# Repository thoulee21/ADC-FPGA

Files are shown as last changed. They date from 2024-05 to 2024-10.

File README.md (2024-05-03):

# Σ-Δ ADC 数模混合电路模型

## 介绍
1. 工程基于lattice提供的方案。  
[lattice提供的方案](https://www.latticesemi.com/products/designsoftwareandip/intellectualproperty/referencedesigns/referencedesign03/simplesigmadeltaadc)  
2. 本工程致力于以下两个目标：  
- 使用实例帮助初学者理解Σ-Δ(Sigma-Delta)ADC的原理  
- 在FPGA上使用简单的外围电路，实现AD转换  
3. 实现所需的器件
- 一个运放或比较器  
- 电容电阻  
- 一个FPGA  

## 系统架构
#### 逻辑结构
输入图片说明  
Σ-Δ ADC一眼看上去，都看不出能AD转换，给人一种“这真的是ADC吗”的感觉。  
本人才疏学浅，大神讲解得更深入：[B站链接](https://www.bilibili.com/video/BV1PV41127QD)  
#### 外围电路
外围电路 批注 2021-11-17 17120.jpg  
显而易见，这是一个比较器，或者是一个工作在比较器状态的运放。  
模拟信号连接至正相输入端，反馈信号经过RC滤波连接至反相输入端，比较器输出连接至FPGA。  
RC滤波器是一个低通滤波器，截止频率与ADC的采样速率和FPGA工作频率有关。
#### 数字设计
外围电路将模拟信号转换为1位的01序列，这样我们就能用数字逻辑去处理模拟信号。  
1. 使用一个累加器，统计一段固定长度序列中1的个数。通过这种方法，可以将01序列转换为一段序列的占空比。累加器宽度由ACCUM_BITS决定。  
2. 占空比信号是有波动的，后端使用一个均值滤波器去除毛刺，滤波器越深，信号速率越低，精度越高。滤波器深度由LPF_DEPTH_BITS决定。  
3. ADC_WIDTH参数贯穿始终，它是ADC的位宽。  
## 使用教程
#### 逻辑仿真
windows环境，需要安装iverilog。  
clone项目，进入`RTL/tb`，运行`make.bat`  
#### 制作实物
k7_fpga.rar是vivado 2019.2的工程，配合`硬件电路/`提供的原理图，可以实现Σ-Δ ADC。  
#### 输出时序
输入图片说明  
## 演示
使用7k325连接外围电路，采集电压，8bit输出。内置逻辑分析仪查看情况。  
sample_rdy高电平脉冲表示一次转换结束，输出结果为0x6d。  
实验的ADC位宽为8bit，量程是0-3.3V，那么实际电压为`0x6d/0xff*3.3=1.41v`，与万用表测量结果吻合。
ILA界面 批注 2021-11-17 184927.jpg

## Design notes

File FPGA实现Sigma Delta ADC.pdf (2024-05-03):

## 通过高速比较器和FPGA逻辑实现 Sigma Delta ADC - 基于电赛综合

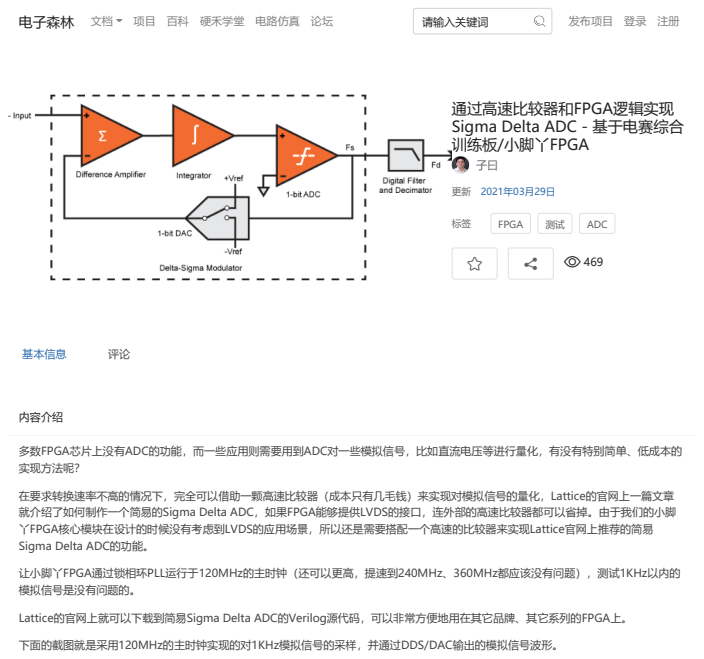
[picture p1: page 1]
训练板/小脚丫FPGA; FPGA; ADC; 基本信息; 内容介绍; 让小脚丫FPGA通过锁相环PLL运行于120MHz的主时钟（还可以更高，提速到240MHz、360MHz都应该没有问题），测试1KHz以内的 模拟信号是没有问题的。; 下面的截图就是采用120MHz的主时钟实现的对1KHz模拟信号的采样，并通过DDS/DAC输出的模拟信号波形。; 电子森林 文档; 项目 百科 硬禾学堂 电路仿真 论坛; 请输入关键词; 发布项目 登录 注册

多数FPGA芯片上没有ADC的功能，而一些应用则需要用到ADC对一些模拟信号，比如直流电压等进行量化，有没有特别简单、低成本的
实现方法呢？

在要求转换速率不高的情况下，完全可以借助一颗高速比较器（成本只有几毛钱）来实现对模拟信号的量化，Lattice的官网上一篇文章
就介绍了如何制作一个简易的Sigma Delta ADC，如果FPGA能够提供LVDS的接口，连外部的高速比较器都可以省掉。由于我们的小脚
丫FPGA核心模块在设计的时候没有考虑到LVDS的应用场景，所以还是需要搭配一个高速的比较器来实现Lattice官网上推荐的简易
Sigma Delta ADC的功能。

Lattice的官网上就可以下载到简易Sigma Delta ADC的Verilog源代码，可以非常方便地用在其它品牌、其它系列的FPGA上。

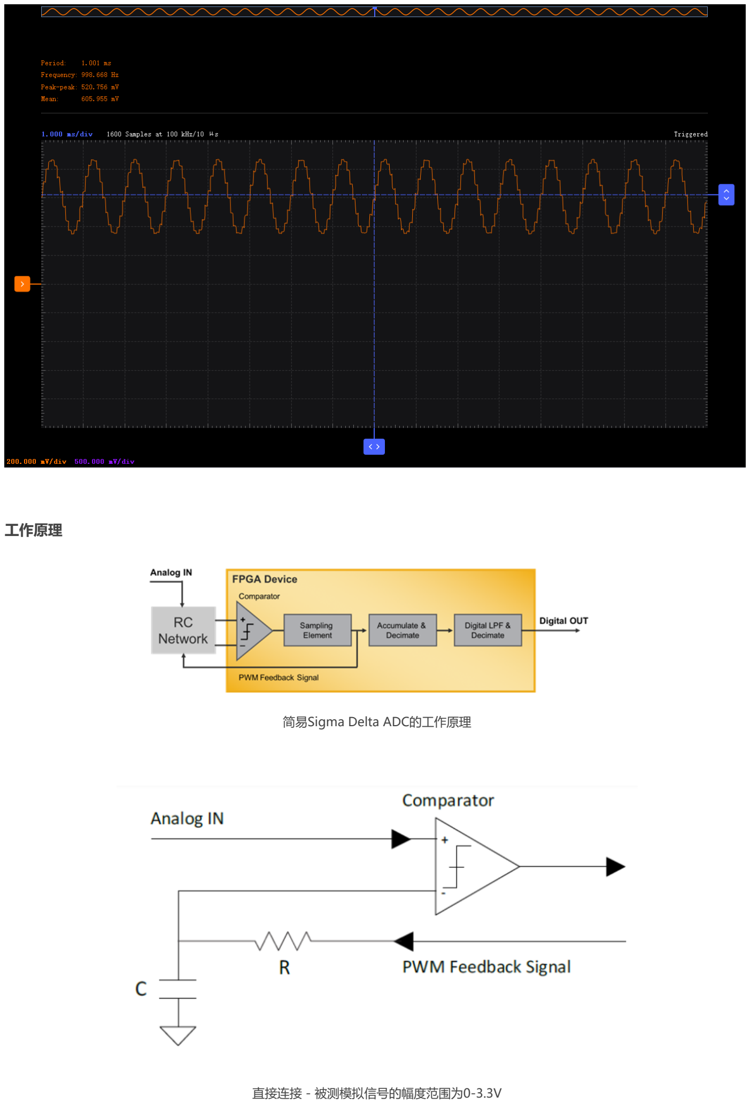
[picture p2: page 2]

### 工作原理

简易Sigma Delta ADC的工作原理

直接连接 - 被测模拟信号的幅度范围为0-3.3V

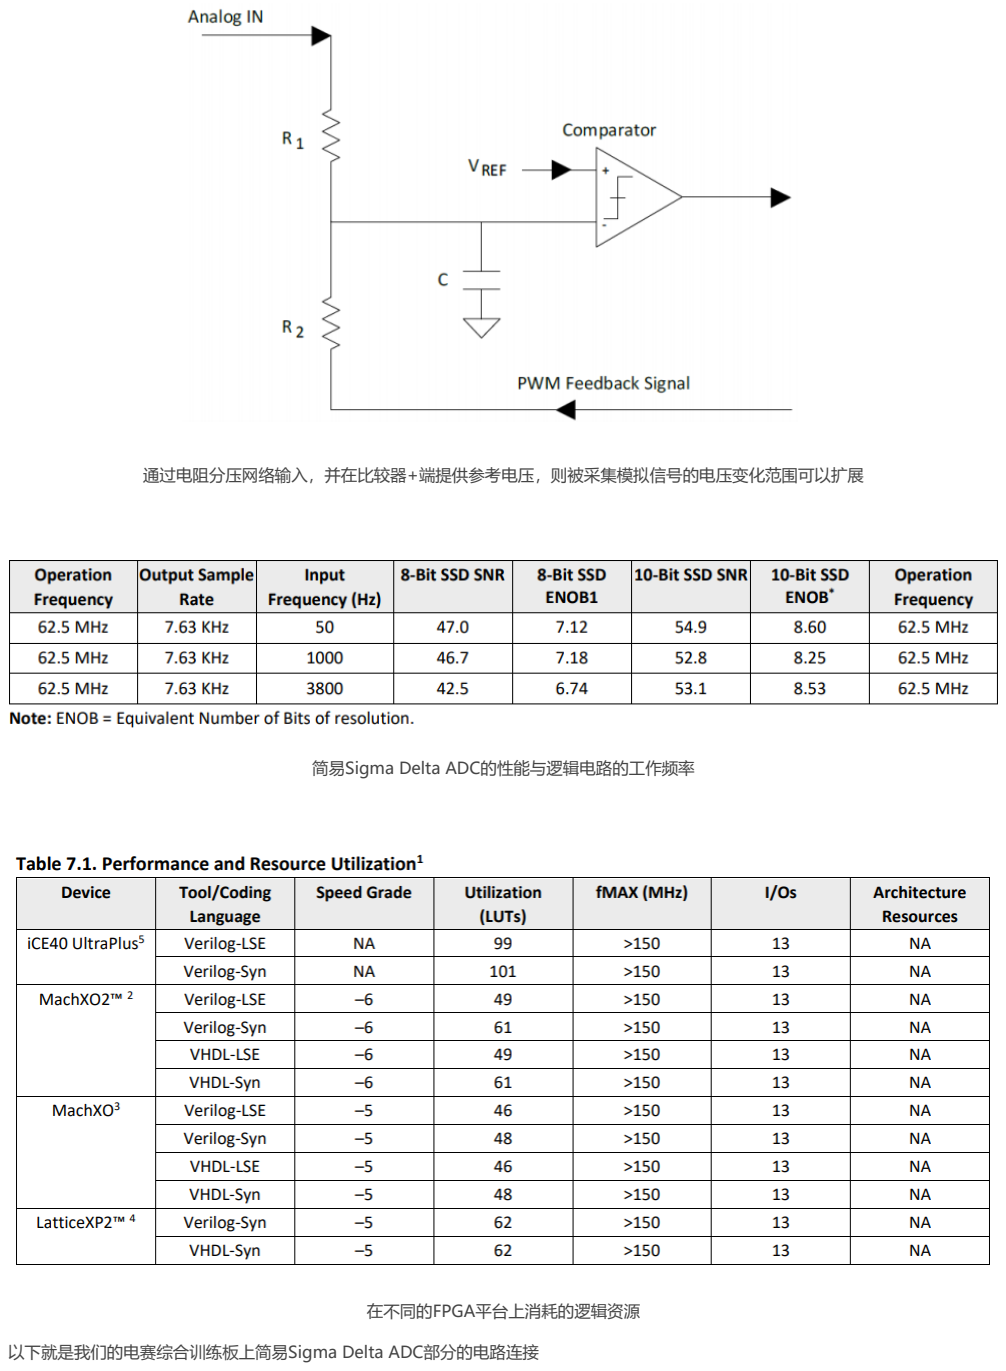
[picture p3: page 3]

通过电阻分压网络输入，并在比较器+端提供参考电压，则被采集模拟信号的电压变化范围可以扩展

简易Sigma Delta ADC的性能与逻辑电路的工作频率

在不同的FPGA平台上消耗的逻辑资源

以下就是我们的电赛综合训练板上简易Sigma Delta ADC部分的电路连接

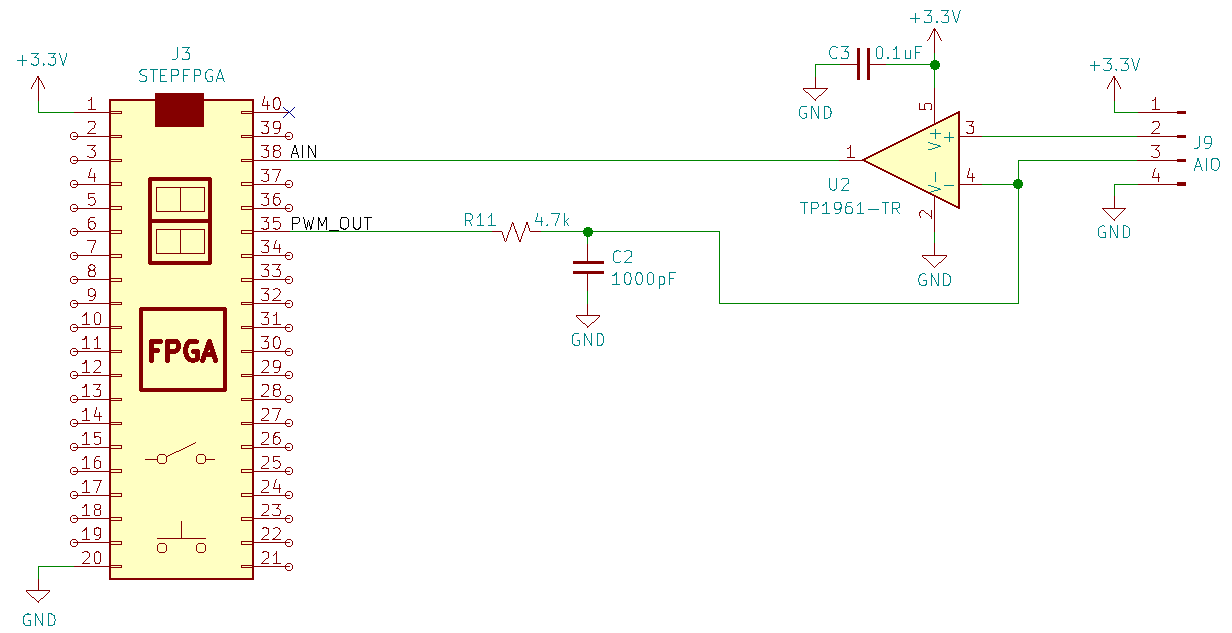
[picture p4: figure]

参考文章：

关键代码：

顶层调用代码：

Sigma Delta ADC顶层程序

wire [7:0] sd_adc_out; // sigma delta adc data output

wire sample_rdy; // flag for adc conversion

ADC_top my_adc(.clk_in(clk_hs),.rstn(1'b1),.digital_out(sd_adc_out), .analog_cmp(comp_in),.analog_out(ad_pwm),.sample_rdy(

assign dac_data | = | sd_adc_out;
assign dac_clk | = | clk_hs; //120MHz generated by PLL
- The basics of sigma delta analog-to-digital converters (https://www.embedded.com/the-basics-of-sigma-delta-analog-to-digital-converters/)
- TEARING INTO DELTA SIGMA ADC’S (https://hackaday.com/2016/07/07/tearing-into-delta-sigma-adcs-part-1/)

// ================================================================== // >>>>>>>>>>>>>>>>>>>>>>> COPYRIGHT NOTICE <<<<<<<<<<<<<<<<<<<<<<<<<
// ------------------------------------------------------------------
// Copyright (c) 2014 by Lattice Semiconductor Corporation
// ALL RIGHTS RESERVED
// ------------------------------------------------------------------//
// Permission:
//
// | Lattice SG Pte. Ltd. grants permission to use this code
// | pursuant to the terms of the Lattice Reference Design License Agreement.
//
//
// Disclaimer:
//
// | This VHDL or Verilog source code is intended as a design reference
// | which illustrates how these types of functions can be implemented.
// | It is the user's responsibility to verify their design for
// | consistency and functionality through the use of formal
// | verification methods. Lattice provides no warranty
// | regarding the use or functionality of this code.
//
// --------------------------------------------------------------------//
// | Lattice SG Pte. Ltd.
// | 101 Thomson Road, United Square #07-02
// | Singapore 307591
//
//
// | TEL: 1-800-Lattice (USA and Canada)
// | +65-6631-2000 (Singapore)
// | +1-503-268-8001 (other locations)
//
// | web: http://www.latticesemi.com/
// | email: techsupport@latticesemi.com
//
// --------------------------------------------------------------------//
// Project: ADC_lvds
// File: | adc_top.v
// Title: | ADC Top Level
// Description: Top level of Analog to Digital Convertor
//
// --------------------------------------------------------------------//
// Revision History :
// --------------------------------------------------------------------
// $Log: RD#rd1066_simple_sigma_delta_adc#rd1066#source#verilog#adc_top.v,v $
// Revision 1.1 2015-02-05 00:00:56-08 mbevinam
// Updated RD Placed in RD Folder. Previous versions are in RD_Dimensions Archive folder. //
// Revision Date
// 1.0 10/12/2009 Initial Revision
//
// --------------------------------------------------------------------

//********************************************************************* //

// ADC Top Level Module
//
//*********************************************************************

module ADC_top (
clk_in,
rstn,
digital_out,
analog_cmp,
analog_out,
sample_rdy);

parameter
ADC_WIDTH | = | 8, | // ADC Convertor Bit Precision
ACCUM_BITS | = | 10, | // 2^ACCUM_BITS is decimation rate of accumulator
LPF_DEPTH_BITS | = | 3, | // 2^LPF_DEPTH_BITS is decimation rate of averager
INPUT_TOPOLOGY | = | 1; | // 0: DIRECT: Analog input directly connected to + input of comparitor
// 1: NETWORK:Analog input connected through R divider to - input of comp.

//input ports
input | clk_in; | // 62.5Mhz on Control Demo board
input | rstn;
input | analog_cmp; | // from LVDS buffer or external comparitor

//output ports
output analog_out; | // feedback to RC network
output sample_rdy;
output [7:0] digital_out; // connected to LED field on control demo bd.

//**********************************************************************
//
// Internal Wire & Reg Signals
//
//**********************************************************************
wire | clk;
wire | analog_out_i;
wire | sample_rdy_i;
wire [ADC_WIDTH-1:0] | digital_out_i;
wire [ADC_WIDTH-1:0] | digital_out_abs;
assign clk | = | clk_in;

//*********************************************************************** //
// SSD ADC using onboard LVDS buffer or external comparitor
//
//*********************************************************************** sigmadelta_adc #(
.ADC_WIDTH(ADC_WIDTH),
.ACCUM_BITS(ACCUM_BITS),
.LPF_DEPTH_BITS(LPF_DEPTH_BITS) )
SSD_ADC(
.clk(clk),

.rstn(rstn),
.analog_cmp(analog_cmp),
.digital_out(digital_out_i), .analog_out(analog_out_i),
.sample_rdy(sample_rdy_i)
);
assign digital_out_abs | = | INPUT_TOPOLOGY | ? | ~digital_out_i : digital_out_i;

//***********************************************************************
//
// output assignments
//
//***********************************************************************
assign digital_out | = | ~digital_out_abs; | // invert bits for LED display
assign analog_out | = | analog_out_i;
assign sample_rdy | = | sample_rdy_i;

endmodule

Sigma Delta ADC主程序

// ================================================================== // >>>>>>>>>>>>>>>>>>>>>>> COPYRIGHT NOTICE <<<<<<<<<<<<<<<<<<<<<<<<<
// ------------------------------------------------------------------
// Copyright (c) 2014 by Lattice Semiconductor Corporation
// ALL RIGHTS RESERVED
// ------------------------------------------------------------------//
// Permission:
//
// | Lattice SG Pte. Ltd. grants permission to use this code
// | pursuant to the terms of the Lattice Reference Design License Agreement.
//
//
// Disclaimer:
//
// | This VHDL or Verilog source code is intended as a design reference
// | which illustrates how these types of functions can be implemented.
// | It is the user's responsibility to verify their design for
// | consistency and functionality through the use of formal
// | verification methods. Lattice provides no warranty
// | regarding the use or functionality of this code.
//
// --------------------------------------------------------------------//
// | Lattice SG Pte. Ltd.
// | 101 Thomson Road, United Square #07-02
// | Singapore 307591
//
//
// | TEL: 1-800-Lattice (USA and Canada)
// | +65-6631-2000 (Singapore)
// | +1-503-268-8001 (other locations)
//
// | web: http://www.latticesemi.com/
// | email: techsupport@latticesemi.com
//
// --------------------------------------------------------------------// --------------------------------------------------------------------//
// Project: Simple Sigma Delta (SSD)
// File: | sigmadelta_adc.v
// Title: | SSD Top Level
// Description: Top level of SSD Analog to Digital Convertor //
// --------------------------------------------------------------------//
// Revision History :
// --------------------------------------------------------------------
// $Log: rd1066#source#verilog#sigmadelta_adc.v,v $
// Revision 1.1 2015-02-05 00:00:52-08 mbevinam
// Updated RD Placed in RD Folder. Previous versions are in RD_Dimensions Archive folder. //
// Revision Date
// 1.0 10/12/2009 Initial Revision
//
// --------------------------------------------------------------------

//*********************************************************************

//
// SSD Top Level Module
//
//*********************************************************************

module sigmadelta_adc (
clk,
rstn,
digital_out,
analog_cmp,
analog_out,
sample_rdy);

parameter
ADC_WIDTH | = | 8, | // ADC Convertor Bit Precision
ACCUM_BITS | = | 10, | // 2^ACCUM_BITS is decimation rate of accumulator
LPF_DEPTH_BITS | = | 3; | // 2^LPF_DEPTH_BITS is decimation rate of averager

//input ports
input | clk; | // sample rate clock
input | rstn; | // async reset, asserted low
input | analog_cmp ; | // input from LVDS buffer (comparitor)

//output ports
output analog_out; | // feedback to comparitor input RC circuit
output sample_rdy; | // digital_out is ready
output [ADC_WIDTH-1:0] | digital_out; | // digital output word of ADC

//**********************************************************************
//
// Internal Wire & Reg Signals
//
//**********************************************************************
reg | delta; | // captured comparitor output
reg [ACCUM_BITS-1:0] | sigma; | // running accumulator value
reg [ADC_WIDTH-1:0] | accum; | // latched accumulator value
reg [ACCUM_BITS-1:0] | counter; | // decimation counter for accumulator
reg | rollover; | // decimation counter terminal count
reg | accum_rdy; | // latched accumulator value 'ready'

//*********************************************************************** //
// SSD 'Analog' Input - PWM
//
// External Comparator Generates High/Low Value
//
//***********************************************************************

always @ (posedge clk)
begin
delta | <= | analog_cmp; | // capture comparitor output
end
assign analog_out | = | delta; | // feedback to comparitor LPF

//*********************************************************************** //
// Accumulator Stage
//
// Adds PWM positive pulses over accumulator period
//
//***********************************************************************

always @ (posedge clk or negedge rstn)
begin
if( ~rstn )
begin
sigma | <= | 0;
accum | <= | 0;
accum_rdy | <= | 0;
end else begin
if (rollover) begin
// latch top ADC_WIDTH bits of sigma accumulator (drop LSBs)
accum | <= | sigma[ACCUM_BITS-1:ACCUM_BITS-ADC_WIDTH];
sigma | <= | delta; | // reset accumulator, prime with current delta value
end else begin
if (&sigma | != | 1'b1) | | // if not saturated
sigma | <= | sigma | + | delta; // accumulate
end
accum_rdy | <= | rollover; | // latch 'rdy' (to align with accum)
end
end

//*********************************************************************** //
// Box filter Average
//
// Acts as simple decimating Low-Pass Filter
//
//***********************************************************************

box_ave #(
.ADC_WIDTH(ADC_WIDTH),
.LPF_DEPTH_BITS(LPF_DEPTH_BITS))
box_ave (
.clk(clk),
.rstn(rstn),
.sample(accum_rdy),
.raw_data_in(accum),
.ave_data_out(digital_out),
.data_out_valid(sample_rdy)
);

//************************************************************************ //
// Sample Control - Accumulator Timing
//
//************************************************************************

always @(posedge clk or negedge rstn)
begin
if( | ~rstn ) begin
counter | <= | 0;

rollover | <= | 0;
end
else begin
counter | <= | counter | + | 1; | // running count
rollover | <= | &counter; | // assert 'rollover' when counter is all 1's
end
end

endmodule

数字低通滤波器模块，做平滑滤波

// ================================================================== // >>>>>>>>>>>>>>>>>>>>>>> COPYRIGHT NOTICE <<<<<<<<<<<<<<<<<<<<<<<<<
// ------------------------------------------------------------------
// Copyright (c) 2014 by Lattice Semiconductor Corporation
// ALL RIGHTS RESERVED
// ------------------------------------------------------------------//
// Permission:
//
// | Lattice SG Pte. Ltd. grants permission to use this code
// | pursuant to the terms of the Lattice Reference Design License Agreement.
//
//
// Disclaimer:
//
// | This VHDL or Verilog source code is intended as a design reference
// | which illustrates how these types of functions can be implemented.
// | It is the user's responsibility to verify their design for
// | consistency and functionality through the use of formal
// | verification methods. Lattice provides no warranty
// | regarding the use or functionality of this code.
//
// --------------------------------------------------------------------//
// | Lattice SG Pte. Ltd.
// | 101 Thomson Road, United Square #07-02
// | Singapore 307591
//
//
// | TEL: 1-800-Lattice (USA and Canada)
// | +65-6631-2000 (Singapore)
// | +1-503-268-8001 (other locations)
//
// | web: http://www.latticesemi.com/
// | email: techsupport@latticesemi.com
//
// --------------------------------------------------------------------// --------------------------------------------------------------------//
// Project: ADC_lvds
// File: | box_ave.v
// Title: | Box Filter Average
// Description: Returns average of last N samples, with /N decimation //
// --------------------------------------------------------------------
//
// Revision History :
// --------------------------------------------------------------------
// $Log: RD#rd1066_simple_sigma_delta_adc#rd1066#source#verilog#box_ave.v,v $
// Revision 1.1 2015-02-05 00:00:54-08 mbevinam
// Updated RD Placed in RD Folder. Previous versions are in RD_Dimensions Archive folder. //
// Revision Date
// 1.0 10/16/2009 S. Hossner Initial Revision
//
// --------------------------------------------------------------------

//*********************************************************************

//
// 'Box' Average
//
// Standard Mean Average Calculation
// Can be modeled as FIR Low-Pass Filter where
// all coefficients are equal to '1'.
//
//*********************************************************************

module box_ave (
clk,
rstn,
sample,
raw_data_in,
ave_data_out,
data_out_valid);

parameter
ADC_WIDTH | = | 8, | // ADC Convertor Bit Precision
LPF_DEPTH_BITS | = | 4; | // 2^LPF_DEPTH_BITS is decimation rate of averager

//input ports
input | clk; | // sample rate clock
input | rstn; | // async reset, asserted low
input | sample; | // raw_data_in is good on rising edge,
input | [ADC_WIDTH-1:0] raw_data_in; | // raw_data input

//output ports
output [ADC_WIDTH-1:0] | ave_data_out; | // ave data output
output data_out_valid; | // ave_data_out is valid, single pulse

reg [ADC_WIDTH-1:0] ave_data_out; //**********************************************************************
//
// Internal Wire & Reg Signals
//
//**********************************************************************
reg [ADC_WIDTH+LPF_DEPTH_BITS-1:0] | accum; | // accumulator
reg [LPF_DEPTH_BITS-1:0] | count; | // decimation count
reg [ADC_WIDTH-1:0] | raw_data_d1; | // pipeline register
reg sample_d1, sample_d2; | // pipeline registers
reg result_valid; | // accumulator result 'valid'
wire accumulate; | // sample rising edge detected
wire latch_result; | // latch accumulator result

//***********************************************************************
//
// Rising Edge Detection and data alignment pipelines
//
//*********************************************************************** always @(posedge clk or negedge rstn)
begin
if( | ~rstn ) begin
sample_d1 | <= | 0;
sample_d2 | <= | 0;
raw_data_d1 | <= | 0;
result_valid | <= | 0;

end else begin
sample_d1 | <= | sample; | // capture 'sample' input
sample_d2 | <= | sample_d1; | // delay for edge detection
raw_data_d1 | <= | raw_data_in; | // pipeline
result_valid | <= | latch_result; | // pipeline for alignment with result
end
end
assign | accumulate | = | sample_d1 | && | !sample_d2; | // 'sample' rising_edge detect
assign | latch_result | = | accumulate | && | (count | == | 0); // latch accum. per decimation count

//***********************************************************************
//
// Accumulator Depth counter
//
//*********************************************************************** always @(posedge clk or negedge rstn)
begin
if( | ~rstn ) begin
count | <= | 0;
end else begin
if (accumulate) count | <= | count | + | 1; | // incr. count per each sample
end
end

//*********************************************************************** //
// Accumulator
//
//*********************************************************************** always @(posedge clk or negedge rstn)
begin
if( | ~rstn ) begin
accum | <= | 0;
end else begin
if (accumulate)
if(count | == | 0) | // reset accumulator
accum | <= | raw_data_d1; | // prime with first value
else
accum | <= | accum | + | raw_data_d1; | // accumulate
end
end

//*********************************************************************** //
// Latch Result
//
// ave = (summation of 'n' samples)/'n' is right shift when 'n' is power of two //
//***********************************************************************
always @(posedge clk or negedge rstn)
begin
if( | ~rstn ) begin
ave_data_out | <= | 0;
end else if (latch_result) begin | // at end of decimation period...
ave_data_out | <= | accum | >> | LPF_DEPTH_BITS; | // ... save accumulator/n result
end
end

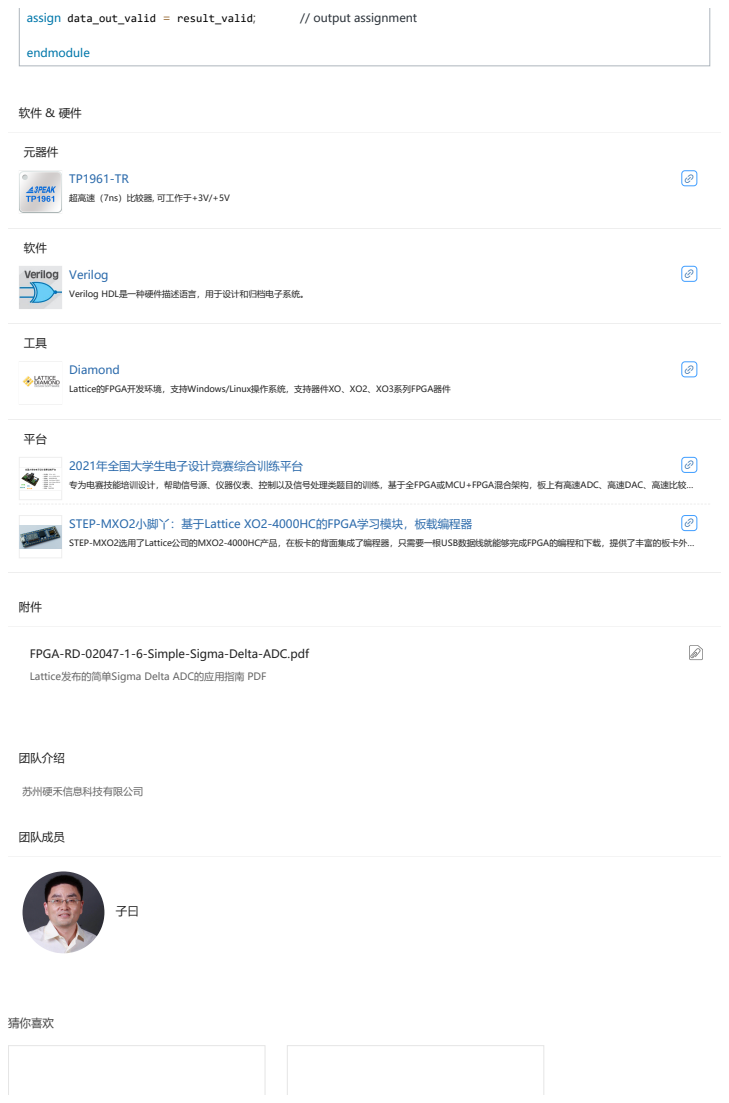
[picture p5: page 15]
assign data_out_valid; result_valid;; // output assignment; endmodule; 元器件; Verilog; Diamond; 2021年全国大学生电子设计竞赛综合训练平台; 团队介绍; 苏州硬禾信息科技有限公司; 团队成员; 猜你喜欢

超高速（7ns）比较器, 可工作于+3V/+5V

Verilog HDL是一种硬件描述语言，用于设计和归档电子系统。

Lattice的FPGA开发环境，支持Windows/Linux操作系统，支持器件XO、XO2、XO3系列FPGA器件

专为电赛技能培训设计，帮助信号源、仪器仪表、控制以及信号处理类题目的训练，基于全FPGA或MCU+FPGA混合架构，板上有高速ADC、高速DAC、高速比较…

STEP-MXO2小脚丫：基于Lattice XO2-4000HC的FPGA学习模块，板载编程器 (https://www.eetree.cn/project/detail/9)

STEP-MXO2选用了Lattice公司的MXO2-4000HC产品，在板卡的背面集成了编程器，只需要一根USB数据线就能够完成FPGA的编程和下载，提供了丰富的板卡外…

FPGA-RD-02047-1-6-Simple-Sigma-Delta-ADC.pdf (https://qn.eetree.cn/FlRufCyIe7GUZQDAtGk-J8RakuxM)
Lattice发布的简单Sigma Delta ADC的应用指南 PDF

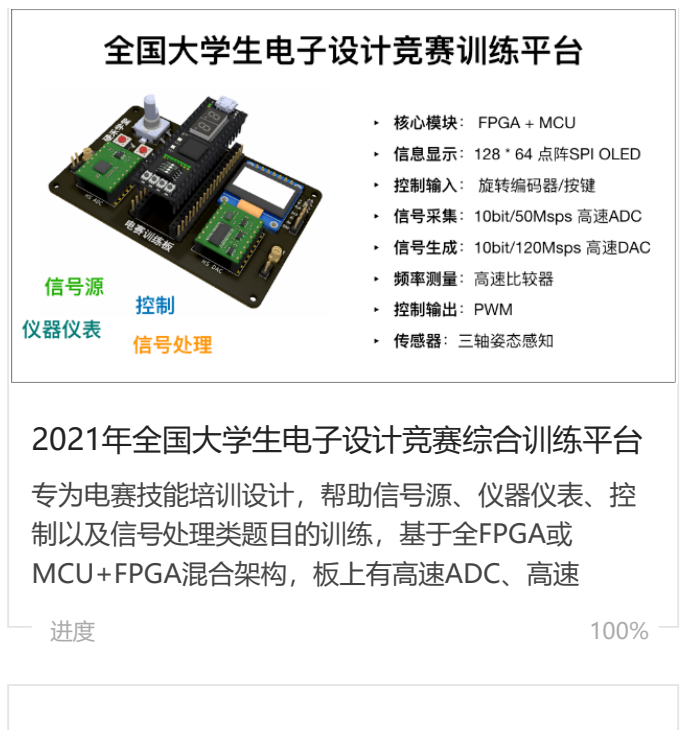
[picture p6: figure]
2021年全国大学生电子设计竞赛综合训练平台; 专为电赛技能培训设计，帮助信号源、仪器仪表、控 制以及信号处理类题目的训练，基于全FPGA或 MCU+FPGA混合架构，板上有高速ADC、高速
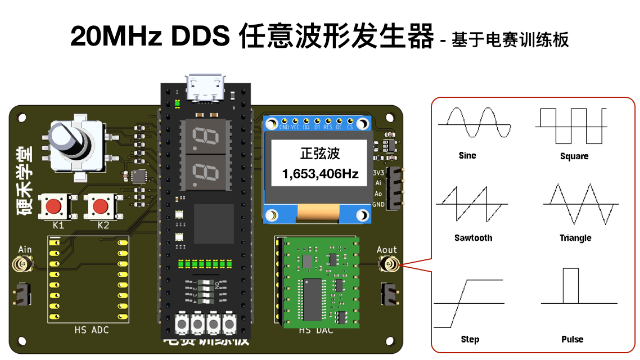
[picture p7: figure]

DDS信号发生器 - 基于电赛综合训练板/小脚丫
FPGA
在电赛综合训练板上实现高速DDS信号发生器的功
能，1个旋转编码器和2个按键控制参数的输入，通过 (https://www.eetree.cn/project/detail/253)

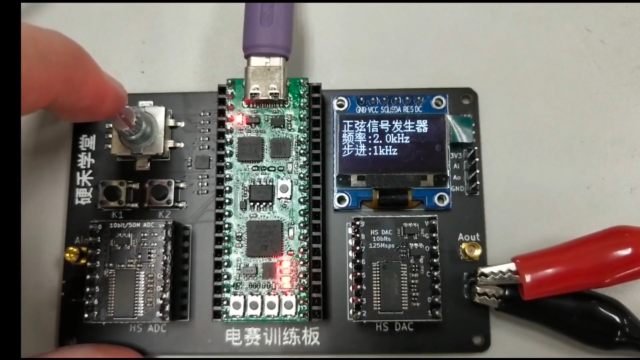
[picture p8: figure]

硬禾学堂STM32+FPGA核心板+电赛综合训练
板完成的DDS正弦信号发生器
本作品采用硬禾学堂的STM32G032 + ICE40UP5K FPGA核心板+电赛综合训练板套装，以单片机为控制 (https://www.eetree.cn/project/detail/361)

@2019 电子森林 苏ICP备19040198号 (https://beian.miit.gov.cn/)

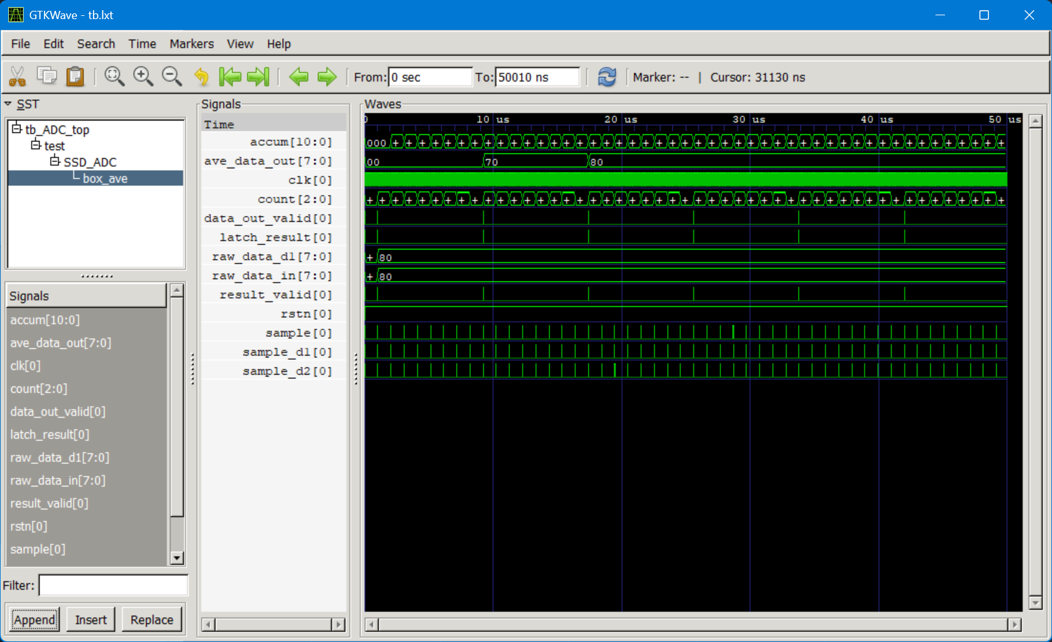
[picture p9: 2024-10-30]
adc_waves.png

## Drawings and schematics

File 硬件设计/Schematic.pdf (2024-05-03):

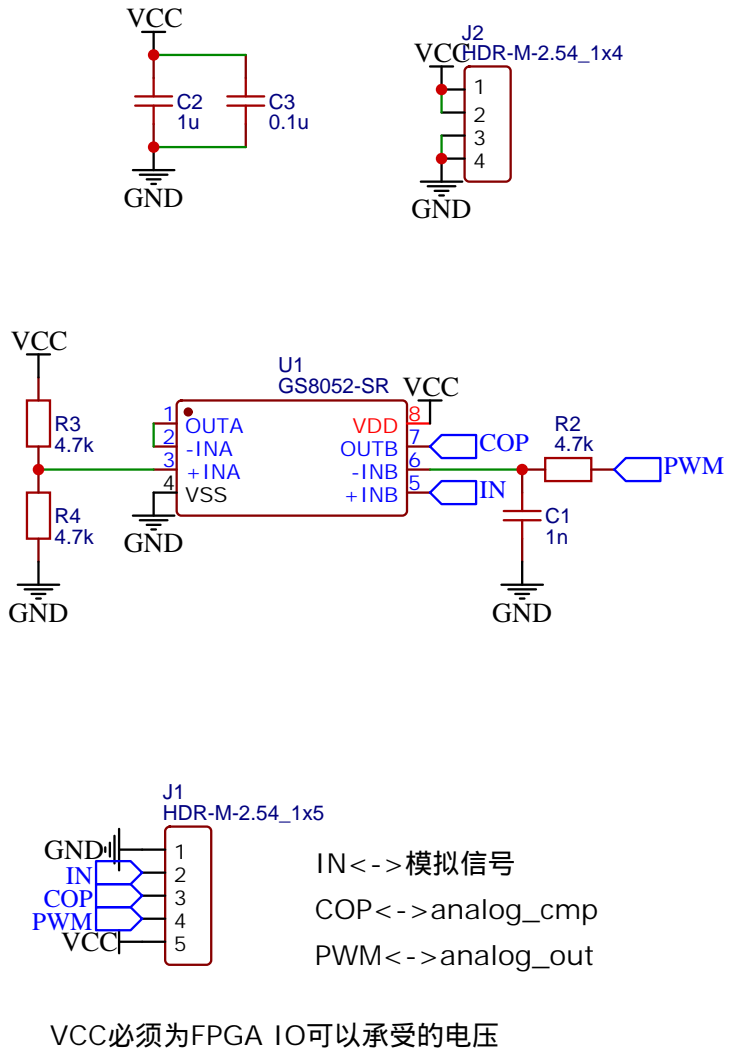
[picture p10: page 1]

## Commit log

2024-05-03 init commit
    [matlab-vivado cic.xlsx]
2024-05-03 Add ADC_8bit.v, capacitor.v, and diode.v modules
2024-05-07 add extracted gerber_pcb
    [Gerber_BoardOutline.GKO, Gerber_BottomLayer.GBL, Gerber_BottomSilkLayer.GBO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]
2024-05-07 [ImgBot] Optimize images
    *Total -- 227.72kb -> 174.82kb (23.23%)
    /adc_waves.png -- 207.53kb -> 157.13kb (24.28%)
    /时序图.jpg -- 20.20kb -> 17.69kb (12.4%)
2024-06-15 feat: add score_board.v 数电大作业篮球计分板代码
